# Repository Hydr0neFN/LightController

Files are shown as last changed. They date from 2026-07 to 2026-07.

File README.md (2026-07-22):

# LightController


ESP32-C3 Super Mini based LED controller with USB-C PD input, DC barrel jack/ terminal block input, two PWM-dimmed LED strip channels, and an addressable NeoPixel output. Apple HomeKit native via [HomeSpan](https://github.com/HomeSpan/HomeSpan), with optional MQTT status reporting.

Built as a one-person project for **Year 1 Period 4 — Power up Yourself** at Hanze University of Applied Sciences, Groningen.

## Hardware

Custom PCB designed in KiCad (design files in [`pcb/`](pcb/)).

### Key Components

| Component | Role |
|---|---|
| ESP32-C3 Super Mini | MCU, WiFi, HomeKit bridge |
| CH224K | USB-C PD sink controller (5V/9V/12V/15V/20V negotiation) |
| AP63205WU | Buck converter, PD/DC rail → 5V for MCU |
| SN74LVC1T45 | 3.3V → 5V level shifter for NeoPixel DIN |
| IRFZ44N × 2 | Low-side N-MOSFETs for LED strip channels |
| UCC27423 | Dual gate driver for MOSFET channels |

### Power Input (Up to 24V tolorance)

- **USB-C PD** via CH224K — negotiates 5V/9V/12V/15V/20V from a PD source
- **DC barrel jack** — direct input (e.g. 12/24V wall adapter), bypasses PD negotiation
- **Terminal Block** — direct input if user have PSU input, bypasses PD negotiation.

Three inputs feed the LED strips directly and the AP63205 buck for 5V MCU power.

### Outputs (All shares same power rail)

- **Channel A** — PWM-dimmed LED strip (low-side MOSFET, enable gate)
- **Channel B** — PWM-dimmed LED strip (low-side MOSFET, enable gate)
- **NeoPixel** — addressable RGB string via level-shifted DIN (SN74LVC1T45)

### PCB History

The PCB was originally designed by [Andrei (ihoneypot)](https://github.com/ihoneypot) as a basic LED controller. I modified the design to add:

- USB-C PD input with CH224K voltage negotiation
- DC barrel jack input as alternative power source
- ESP8266 → ESP32-C3 Super Mini swap (HomeKit-capable, smaller footprint)
- Unified power routing: three input paths merged to one rail, split to two LED strip outputs + NeoPixel output
- 3.3V→5V level shifter for NeoPixel data line

### PD Status — Not Working

The CH224K PD negotiation circuit is **currently disabled** (`ENABLE_PD 0` in config). During bringup we burned several CH224K chips and discovered through debugging:

- The 1kΩ resistor from VBUS to VDD acts as a voltage divider but the 0805 package cannot dissipate the power at higher voltages (P = V²/R; at 20V that's 0.4W through a 0.1W-rated resistor — it overheats and eventually burns)
- USB-C D+/D- must be shorted on the chip side for proper enumeration
- The USB-C connector requires careful reflow; loose joints cause intermittent communication

**Fixes needed for a future revision:**
- Use a power resistor rated for ≥0.4W (or ≥0.15W if limiting to 12V max)
- Short D+/D- on the CH224K side, remove the data line routing from the USB-C connector
- The firmware PD controller (`PDController.h`) is implemented but untested on hardware — only the hardware needs fixing before end-to-end testing can happen

## Firmware

PlatformIO project targeting `nologo_esp32c3_super_mini` via the [pioarduino](https://github.com/pioarduino/platform-espressif32) fork (arduino-esp32 core 3.3.9, ESP-IDF 5.5.4).

### Features

- **HomeKit native** — two dimmable lightbulbs (CH A/B) + one RGB lightbulb (NeoPixel), bridged accessory
- **PD voltage switching** — load-shedding before rail transition, NVS persistence for brown-out recovery (disabled until hardware fix)
- **MQTT status** — periodic JSON status publish, network voltage control via `lightctrl/cmd/voltage`
- **Web Log** — live status/log at `http://<device-ip>/status`
- **Serial CLI** — `V0`..`V4` for PD voltage, `J` for status JSON, plus full HomeSpan command set
- **OTA updates** — via HomeSpan's built-in OTA

### Building

1. Copy `src/config.h.example` → `src/config.h`
2. Edit `config.h` — set your WiFi credentials, HomeKit pairing code, MQTT broker IP, and NeoPixel count
3. Build and flash:

```bash
pio run -t upload
pio device monitor
```

### Pin Map

| GPIO | Function |
|---|---|
| 0 | CH B PWM (strapping pin) |
| 1 | CH A PWM |
| 2 | CH A enable |
| 3 | CH B enable |
| 4 | NeoPixel DIN |
| 5 | CH224K CFG1 |
| 6 | CH224K CFG3 |
| 7 | CH224K CFG2 |
| 8 | Status LED (boot strapping) |
| 21 | CH224K PG (Power Good) |

### Project Structure

```
├── src/
│   ├── main.cpp           # Setup, loop, serial commands, status LED
│   ├── config.h.example   # Configuration template (copy to config.h)
│   ├── Lights.h           # DimmableChannel + NeoStrip HomeKit services
│   ├── PDController.h     # CH224K PD voltage negotiation driver
│   └── StatusReporter.h   # MQTT publisher + JSON status builder
├── pcb/                   # KiCad 10 design files
│   ├── LEDController.kicad_sch   # Schematic
│   ├── LEDController.kicad_pcb   # PCB layout
│   ├── LEDController.kicad_pro   # Project file
│   ├── LEDController.csv         # BOM
│   ├── LEDController.pretty/     # Custom footprints (ESP32-C3 module, UCC27423)
│   ├── LedPannel.pretty/        # Custom footprints (PowerDI diode, inductor)
│   └── Prod/                    # Production Gerber files
└── platformio.ini
```

## Dependencies

| Library | Version | Purpose |
|---|---|---|
| [HomeSpan](https://github.com/HomeSpan/HomeSpan) | ≥2.1.0 | HomeKit accessory framework |
| [PubSubClient](https://github.com/knolleary/pubsubclient) | ≥2.8 | MQTT client |

## Credits

- **PCB base design** — [Andrei (ihoneypot)](https://github.com/ihoneypot)
- **Modifications, firmware, bringup** — [Yu-I (Hydr0neFN)](https://github.com/Hydr0neFN)

## License

MIT

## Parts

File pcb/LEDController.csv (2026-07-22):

Reference | Qty | Value | DNP | Exclude from BOM | Exclude from Board | Footprint | Datasheet
C1 | 1 | C10uF |  |  |  | Capacitor_SMD:C_0805_2012Metric
C2 | 1 | C100nF |  |  |  | Capacitor_SMD:C_0805_2012Metric
C3,C4 | 2 | C22uF |  |  |  | Capacitor_SMD:C_1206_3216Metric
C5,C6 | 2 | 10uF |  |  |  | Capacitor_SMD:C_0805_2012Metric
C7 | 1 | 1uF |  |  |  | Capacitor_SMD:C_0805_2012Metric
D1 | 1 | SS54 |  |  |  | Diode_SMD:D_SMA
H1,H2,H3,H4 | 4 | MountingHole_Pad |  |  |  | MountingHole:MountingHole_3.2mm_M3_Pad_Via
J1 | 1 | USB_C_Receptacle |  |  |  | Connector_USB:USB_C_Receptacle_HRO_TYPE-C-31-M-12
J2 | 1 | Barrel_Jack_Switch_MountingPin |  |  |  | Connector_BarrelJack:BarrelJack_Kycon_KLDX-0202-xC_Horizontal
J3,J4,J5 | 3 | Screw_Terminal_01x02 |  |  |  | TerminalBlock:TerminalBlock_MaiXu_MX126-5.0-02P_1x02_P5.00mm
J6 | 1 | Screw_Terminal_01x03 |  |  |  | TerminalBlock:TerminalBlock_MaiXu_MX126-5.0-03P_1x03_P5.00mm
L1 | 1 | L4.7uH |  |  |  | Inductor_SMD:L_6.3x6.3_H3
Q1,Q2 | 2 | IRFZ44N |  |  |  | Package_TO_SOT_THT:TO-220-3_Vertical | http://www.irf.com/product-info/datasheets/data/irf540n.pdf
R1,R2,R3 | 3 | R1K |  |  |  | Resistor_SMD:R_0805_2012Metric
R4,R5,R6,R7,R8,R9,R10,R11 | 8 | 10K |  |  |  | Resistor_SMD:R_0805_2012Metric
U1 | 1 | AP63205WU |  |  |  | Package_TO_SOT_SMD:TSOT-23-6 | https://www.diodes.com/assets/Datasheets/AP63200-AP63201-AP63203-AP63205.pdf
U2 | 1 | ESP32-C3_SUPERMINI_SMD |  |  |  | LEDController:MODULE_ESP32-C3_SUPERMINI_SMD
U3 | 1 | CH224K |  |  |  | Package_SO:SSOP-10-1EP_3.9x4.9mm_P1mm_EP2.1x3.3mm
U4 | 1 | UCC2742x |  |  |  | LEDController:UCC2742x
U5 | 1 | SN74LVC1T45DBV |  |  |  | Package_TO_SOT_SMD:SOT-23-6

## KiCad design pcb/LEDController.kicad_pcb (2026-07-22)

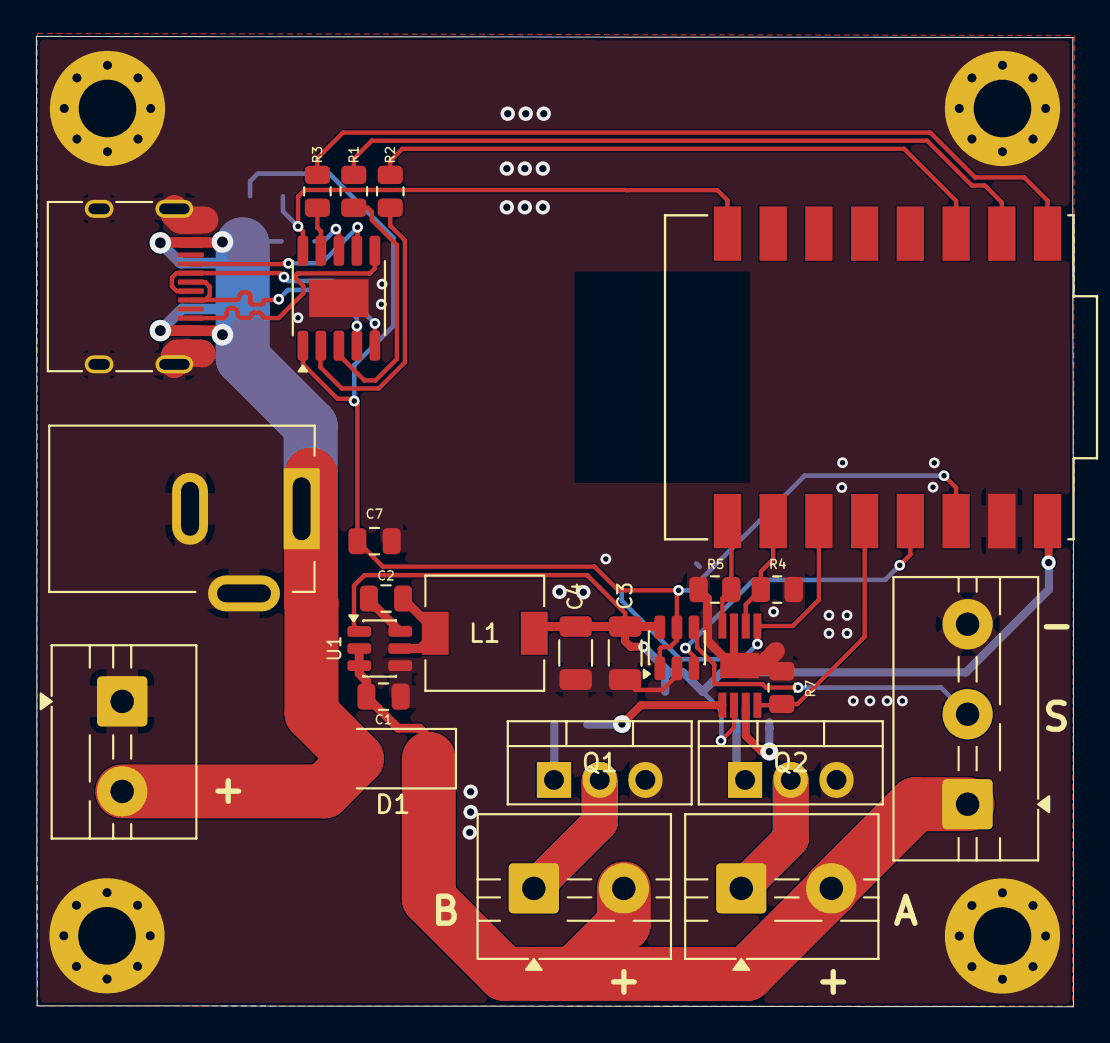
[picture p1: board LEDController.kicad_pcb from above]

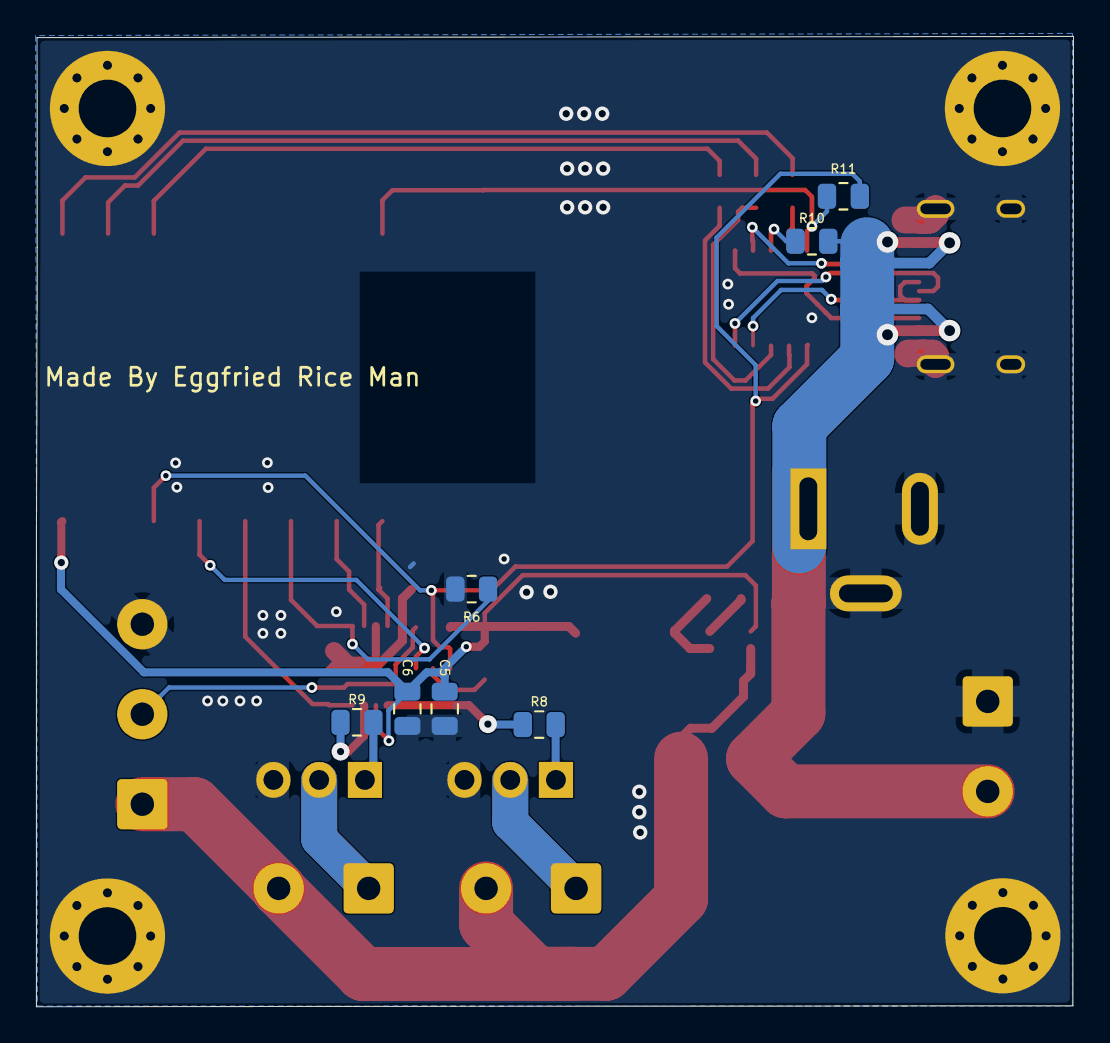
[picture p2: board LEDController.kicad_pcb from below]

Board: 2 copper layers, 57.6 x 53.9 mm, 37 parts (7 on the bottom side), 31 nets.

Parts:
C1: C10µF; C_0805_2012Metric
C2: C100nF; C_0805_2012Metric
C3, C4: C22µF; C_1206_3216Metric
C5, C6: 10uF; C_0805_2012Metric
C7: 1uF; C_0805_2012Metric
D1: SS54; D_SMA
H1, H2, H3, H4: MountingHole_Pad; MountingHole_3.2mm_M3_Pad_Via
J1: USB_C_Receptacle; USB_C_Receptacle_HRO_TYPE-C-31-M-12
J2: Barrel_Jack_Switch_MountingPin; BarrelJack_Kycon_KLDX-0202-xC_Horizontal
J3, J4, J5: Screw_Terminal_01x02; TerminalBlock_MaiXu_MX126-5.0-02P_1x02_P5.00mm
J6: Screw_Terminal_01x03; TerminalBlock_MaiXu_MX126-5.0-03P_1x03_P5.00mm
L1: L4.7µH; L_6.3x6.3_H3
Q1, Q2: IRFZ44N; TO-220-3_Vertical
R1, R2, R3: R1K; R_0805_2012Metric
R4, R5, R6, R7, R8, R9, R10, R11: 10K; R_0805_2012Metric
U1: AP63205WU; TSOT-23-6
U2: ESP32-C3_SUPERMINI_SMD; MODULE_ESP32-C3_SUPERMINI_SMD
U3: CH224K; SSOP-10-1EP_3.9x4.9mm_P1mm_EP2.1x3.3mm
U4: UCC2742x
U5: SN74LVC1T45DBV; SOT-23-6

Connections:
+3.3V: C7.1, R11.2, U2.3.3 (3V3), U3.1 (VDD), U5.1 (VCCA), U5.5 (DIR)
+5V: C3.2, C4.2, C5.1, C6.1, L1.2, U1.1 (FB), U2.5V, U4.6 (VDD), U5.6 (VCCB)
/CFG1: R3.2, U3.9 (CFG1)
/CFG2: R2.2, U3.2 (CFG2)
/CFG3: R1.2, U3.3 (CFG3)
/ENBA: R6.2, U2.2 (GPIO2), U4.1 (ENBA)
/ENBB: R7.2, U2.3 (GPIO3), U4.8 (ENBB)
/PG: R11.1, U2.21 (GPIO21), U3.10 (PG)
/USB_CC1: J1.A5 (CC1), U3.7 (CC1)
/USB_CC2: J1.B5 (CC2), U3.6 (CC2)
/USB_D+: J1.A6 (D+), J1.B6 (D+), U3.4 (DP)
/USB_D-: J1.A7 (D-), J1.B7 (D-), U3.5 (DM)
/VBUS_PD: D1.2 (A), J1.A4 (VBUS), J1.A9 (VBUS), J1.B4 (VBUS), J1.B9 (VBUS), J2.1, J3.2, R10.2
/VIN: C1.1, D1.1 (K), J4.2, J5.2, J6.1, U1.2 (EN), U1.3 (IN)
DRAINA: J4.1, Q2.2 (D)
DRAINB: J5.1, Q1.2 (D)
GATEA: Q2.1 (G), R9.2
GATEB: Q1.1 (G), R8.2
GND: C1.2, C3.1, C4.1, C5.2, C6.2, C7.2, H1.1 (1_1), H2.1 (1_1), H3.1 (1_1), H4.1 (1_1), J1.A1 (GND), J1.A12 (GND), J1.B1 (GND), J1.B12 (GND), J1.SH (SHIELD), J2.2, J2.3, J3.1, J6.3, Q1.3 (S), Q2.3 (S), R4.1, R5.2, R6.1, R7.1, U1.4 (GND), U2.G (GND), U3.11 (GND), U4.3 (GND), U4.9, U5.2 (GND)
NEOPIXEL_DIN: U2.4 (GPIO4), U5.3 (A)
NEO_5V_DIN: J6.2, U5.4 (B)
unnamed: C2.2, U1.6 (BST)
unnamed: C2.1, L1.1, U1.5 (SW)
unnamed: R3.1, U2.5 (GPIO5)
unnamed: R1.1, U2.6 (GPIO6)
unnamed: R2.1, U2.7 (GPIO7)
unnamed: R10.1, U3.8 (VBUS)
unnamed: R9.1, U4.7 (OUTA)
unnamed: R8.1, U4.5 (OUTB)
PWM1: R4.2, U2.1 (GPIO1), U4.2 (INA)
PWM2: R5.1, U2.0 (GPIO0), U4.4 (INB)

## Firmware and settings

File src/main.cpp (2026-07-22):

// ============================================================================
//  LightController - ESP32-C3 Super Mini
//
//  - PD/DC dual input; CH224K negotiates the PD rail from a user-selected
//    voltage (persisted in NVS so a brown-out mid-switch self-recovers).
//  - Two PWM-dimmed LED strip channels (CH A / CH B) as HomeKit lightbulbs.
//  - One NeoPixel string (RGB) as a HomeKit lightbulb.
//  - HomeSpan Web Log for live status/log over HTTP (replaces telnet):
//        http://<device-ip>/status
//  - Optional MQTT status publishing (see config.h ENABLE_MQTT).
//
//  Serial CLI (115200): type 'V0'..'V4' to switch PD voltage
//    0=5V 1=9V 2=12V 3=15V 4=20V   ('?' for full HomeSpan command list)
// ============================================================================
#include <Arduino.h>
#include <WiFi.h>
#include "HomeSpan.h"

#if PD_DISABLE_BROWNOUT
  #include "soc/soc.h"
  #include "soc/rtc_cntl_reg.h"
#endif

#include "config.h"
#include "PDController.h"
#include "Lights.h"
#include "StatusReporter.h"

// ---- Globals ---------------------------------------------------------------
PDController     pd;
DimmableChannel *chA = nullptr;
DimmableChannel *chB = nullptr;
NeoStrip        *neo = nullptr;
StatusReporter  *status = nullptr;

// ---- Switch PD voltage with load-shedding (shared by serial + MQTT) ----------
void switchVoltage(PDVoltage v) {
  if (!PDController::enabled()) {
    WEBLOG("Voltage cmd ignored: PD nego disabled (DC-only)");
    Serial.printf("PD disabled (DC-only) - voltage command ignored\n");
    return;
  }
  WEBLOG("PD switch -> %s (shedding LED load)", PDController::voltageName(v));
  chA->hardOff();
  chB->hardOff();
  delay(20);                        // let load drop before the rail moves

  bool ok = pd.setVoltage(v);       // persists to NVS first, drives CFG, waits PG
  delay(50);                        // let the new rail settle

  chA->refresh();
  chB->refresh();

  if (neo->isOn() && v != PD_5V)
    WEBLOG("WARNING: NeoPixel rail is now %s, not 5V", PDController::voltageName(v));

  WEBLOG("PD now %s, PG=%s", PDController::voltageName(pd.current()),
         ok ? "good" : "TIMEOUT");
  Serial.printf("PD -> %s  PG=%s\n", PDController::voltageName(pd.current()),
                ok ? "good" : "TIMEOUT");
}

// ---- Serial command: switch PD voltage --------------------------------------
void setVoltageCmd(const char *buf) {
  int n = atoi(buf + 1);            // buf is e.g. "V4"
  if (n < PD_5V || n > PD_20V) {
    Serial.printf("Usage: V<0-4>  (0=5V 1=9V 2=12V 3=15V 4=20V)\n");
    return;
  }
  switchVoltage((PDVoltage)n);
}

// ---- Serial command: print status JSON --------------------------------------
void statusCmd(const char *buf) {
  char j[256];
  status->buildJson(j, sizeof(j));
  Serial.println(j);
}

// ---- On-board status LED -----------------------------------------------------
// OFF when normal. Blinks fast on PD power-good fault, slow on WiFi loss.
static inline void ledDrive(bool lit) {
  digitalWrite(PIN_STATUS_LED, lit ? STATUS_LED_ON_LEVEL : !STATUS_LED_ON_LEVEL);
}

void updateStatusLed() {
  static uint32_t last = 0;
  static bool     on   = false;

  uint32_t period;
  if (!pd.powerGood())                    period = STATUS_BLINK_PG_MS;    // priority
  else if (WiFi.status() != WL_CONNECTED) period = STATUS_BLINK_WIFI_MS;
  else { on = false; ledDrive(false); return; }                          // normal: off

  uint32_t now = millis();
  if (now - last >= period) {
    last = now;
    on = !on;
    ledDrive(on);
  }
}

void setup() {
#if PD_DISABLE_BROWNOUT
  WRITE_PERI_REG(RTC_CNTL_BROWN_OUT_REG, 0);   // disable BOD before anything else
#endif

  pinMode(PIN_STATUS_LED, OUTPUT);
  ledDrive(false);                              // start dark

  Serial.begin(115200);

  // Negotiate the PD rail first so downstream loads see the intended voltage.
  pd.begin();

  // ---- HomeSpan / WiFi ----
  homeSpan.setWifiCredentials(WIFI_SSID, WIFI_PASSWORD);
  homeSpan.setPairingCode(HK_PAIRING_CODE);
  homeSpan.enableOTA();
  homeSpan.enableWebLog(WEBLOG_MAX_ENTRIES, NTP_SERVER, TIME_ZONE, WEBLOG_URL);

  homeSpan.begin(Category::Bridges, HK_DEVICE_NAME, HK_HOSTNAME);

  // Bridge accessory
  new SpanAccessory();
    new Service::AccessoryInformation();
      new Characteristic::Identify();
      new Characteristic::Name(HK_DEVICE_NAME);

  // CH A
  new SpanAccessory();
    new Service::AccessoryInformation();
      new Characteristic::Identify();
      new Characteristic::Name(HK_NAME_CHA);
    chA = new DimmableChannel(PIN_CHA_PWM, PIN_CHA_EN, HK_NAME_CHA);

  // CH B
  new SpanAccessory();
    new Service::AccessoryInformation();
      new Characteristic::Identify();
      new Characteristic::Name(HK_NAME_CHB);
    chB = new DimmableChannel(PIN_CHB_PWM, PIN_CHB_EN, HK_NAME_CHB);

  // NeoPixel
  new SpanAccessory();
    new Service::AccessoryInformation();
      new Characteristic::Identify();
      new Characteristic::Name(HK_NAME_NEO);
    neo = new NeoStrip(PIN_NEOPIXEL_DIN, NEOPIXEL_COUNT, HK_NAME_NEO);

  // Status reporter (MQTT + JSON helper). Wire network voltage control.
  status = new StatusReporter(&pd, chA, chB, neo);
  status->setVoltageHandler(switchVoltage);
  status->begin();

  // Custom serial commands
  new SpanUserCommand('V', "<0-4> - set PD voltage (0=5V 1=9V 2=12V 3=15V 4=20V)",
                      setVoltageCmd);
  new SpanUserCommand('J', "- print status JSON", statusCmd);

  if (PDController::enabled()) {
    WEBLOG("Boot complete. PD=%s PG=%s", PDController::voltageName(pd.current()),
           pd.powerGood() ? "good" : "BAD");
  } else {
    WEBLOG("Boot complete. DC-only mode (PD nego disabled)");
  }
}

void loop() {
  homeSpan.poll();
  status->poll();
  updateStatusLed();
}

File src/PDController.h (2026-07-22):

#pragma once
#include <Arduino.h>
#include <Preferences.h>
#include "config.h"

// ============================================================================
//  CH224K USB-PD sink controller
//
//  CFG truth table (requested voltage), CFG bit meaning: 1 = high, 0 = low.
//    5V : CFG1=1  CFG2=x  CFG3=x
//    9V : CFG1=0  CFG2=0  CFG3=0
//    12V: CFG1=0  CFG2=0  CFG3=1
//    15V: CFG1=0  CFG2=1  CFG3=1
//    20V: CFG1=0  CFG2=1  CFG3=0
//
//  Wiring: each CFG line is GPIO -> 1k -> CH224K, no external pull resistors.
//  Drive convention: push-pull through the 1k series, "1" = HIGH, "0" = LOW.
//  Active drive is used (rather than high-Z) because the lines have no external
//  pull; the 1k limits current into the CH224K CFG inputs.
//
//  PG (Power Good): open-drain, active LOW. LOW => requested rail is present.
// ============================================================================

enum PDVoltage : uint8_t { PD_5V = 0, PD_9V = 1, PD_12V = 2, PD_15V = 3, PD_20V = 4 };

class PDController {
public:
  static constexpr bool enabled() { return ENABLE_PD; }

  void begin() {
    if (!enabled()) {
      // DC-only: leave CFG pins high-impedance, don't touch the CH224K, and
      // skip PG (no PD source => PG would float and read as a fault).
      pinMode(PIN_CFG1, INPUT);
      pinMode(PIN_CFG2, INPUT);
      pinMode(PIN_CFG3, INPUT);
      return;
    }

    pinMode(PIN_PG, INPUT_PULLUP);  // external 10k pull-up already present

    _prefs.begin("pd", false);
#if PD_FORCE_DEFAULT
    // Hard override: always boot at the compile-time constant.
    _current = (PDVoltage)PD_DEFAULT_VOLTAGE;
    _prefs.putUChar("volt", (uint8_t)_current);
#else
    // Restore last requested voltage (survives a brown-out reset mid-switch).
    _current = (PDVoltage)_prefs.getUChar("volt", (uint8_t)PD_DEFAULT_VOLTAGE);
#endif
    applyCfg(_current);
  }

  PDVoltage current() const { return _current; }

  // PG is active LOW. In DC-only mode there is no PD source, so report "good"
  // unconditionally (prevents a false fault on the status LED / status JSON).
  bool powerGood() const {
    if (!enabled()) return true;
    return digitalRead(PIN_PG) == LOW;
  }

  // Request a new voltage. Persists FIRST so a transient reset recovers to the
  // intended rail. Returns true if PG asserted within PD_PG_TIMEOUT_MS.
  // NOTE: caller should drop the LED loads (EN low) before calling, to ease the
  // transient on the shared 5V buck. See main.cpp setVoltageCmd().
  bool setVoltage(PDVoltage v) {
    if (!enabled()) return true;           // DC-only: no-op
    _prefs.putUChar("volt", (uint8_t)v);   // persist before touching the rail
    applyCfg(v);
    _current = v;
    return waitPowerGood(PD_PG_TIMEOUT_MS);
  }

  bool waitPowerGood(uint32_t timeoutMs) {
    uint32_t t0 = millis();
    while (!powerGood()) {
      if (millis() - t0 > timeoutMs) return false;
      delay(2);
    }
    return true;
  }

  static const char *voltageName(PDVoltage v) {
    switch (v) {
      case PD_5V:  return "5V";
      case PD_9V:  return "9V";
      case PD_12V: return "12V";
      case PD_15V: return "15V";
      case PD_20V: return "20V";
    }
    return "?";
  }

  // Approximate nominal millivolts, for status reporting.
  static uint32_t voltageMilliVolts(PDVoltage v) {
    switch (v) {
      case PD_5V:  return 5000;
      case PD_9V:  return 9000;
      case PD_12V: return 12000;
      case PD_15V: return 15000;
      case PD_20V: return 20000;
    }
    return 0;
  }

private:
  // Set CFG pins for the requested voltage (1 = float high, 0 = drive low).
  void applyCfg(PDVoltage v) {
    uint8_t c1, c2, c3;
    switch (v) {
      case PD_5V:  c1 = 1; c2 = 1; c3 = 1; break;  // CFG2/3 are don't-care -> float
      case PD_9V:  c1 = 0; c2 = 0; c3 = 0; break;
      case PD_12V: c1 = 0; c2 = 0; c3 = 1; break;
      case PD_15V: c1 = 0; c2 = 1; c3 = 1; break;
      case PD_20V: c1 = 0; c2 = 1; c3 = 0; break;
      default:     c1 = 1; c2 = 1; c3 = 1; break;  // safest fallback -> 5V
    }
    cfgWrite(PIN_CFG1, c1);
    cfgWrite(PIN_CFG2, c2);
    cfgWrite(PIN_CFG3, c3);
  }

  // CFG1..3 are GPIO -> 1k -> CH224K with no external pull resistors.
  // Drive push-pull through the 1k series: bit==1 -> HIGH, bit==0 -> LOW.
  // Active drive (not high-Z) gives a deterministic level on lines that have no
  // external pull; the 1k limits current into the CH224K CFG inputs.
  static void cfgWrite(uint8_t pin, uint8_t bit) {
    pinMode(pin, OUTPUT);
    digitalWrite(pin, bit ? HIGH : LOW);
  }

  Preferences _prefs;
  PDVoltage   _current = PD_DEFAULT_VOLTAGE;
};

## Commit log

2026-07-22 Initial commit: ESP32-C3 LED controller with HomeKit, KiCad PCB
    Firmware: HomeSpan-based HomeKit bridge with two PWM LED channels,
    NeoPixel RGB output, CH224K PD voltage negotiation (disabled pending
    hardware fix), MQTT status reporting, and web log.
    PCB: KiCad 8 design files with custom footprints and production gerbers.
    Original PCB base by Andrei (ihoneypot), modified to add USB-C PD input,
    DC barrel jack, ESP32-C3 swap, unified power routing, and NeoPixel output.
    [LEDController-B_Cu.gbr, LEDController-B_Mask.gbr, LEDController-B_Paste.gbr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]
2026-07-22 Fix post-push issues: sanitize pairing code, correct KiCad version, clarify PD status
    - Replace real HomeKit pairing code in config.h.example with placeholder
    - KiCad 8 → KiCad 10 (matches actual sym-lib-table path)
    - PD firmware: clarify untested on hardware (chips burned before validation)
2026-07-22 Updated details
    Added addition details to power related
